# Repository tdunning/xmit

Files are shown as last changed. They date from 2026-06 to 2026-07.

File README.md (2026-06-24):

# XMIT - New tools for old jobs

This repository has design files and (soon) code for a direct synthesis digital 
mode transmitter optimized for use on amateur bands. It should work well up to 
2m. The novelty here relative to other systems like the [QDX](https://qrp-labs.com/qdx.html)
lies in a few areas:

a) the use of [74LVC2G157](https://www.ti.com/lit/ds/symlink/sn74lvc2g157.pdf) to generate differential drive for a differential
driver such as the [THS6232](https://www.ti.com/lit/ds/symlink/ths6232.pdf) which can
directly drive most balanced antennas without a balun at up to about 5W. This design
avoids the need for fancy gate drive or paralleling FETs in favor of SMT packaging everywhere. 

b) the use of SMT inductors and SMT analog switches such as the 
[74lvc2g53](https://www.ti.com/lit/ds/symlink/sn74lvc2g53.pdf) or 
[74lvc1g66](https://www.ti.com/lit/ds/symlink/sn74lvc1g66.pdf).
This change is not earth-shattering, but it allows a much tighter all-SMT design with as much as 80dB suppression of harmonics.
The high degree of suppression is achieved by using a filter tuned to put the response zeros directly on the harmonics
and careful filter layout to suppress parasitic coupling.

# Transmit filtering

The design of the transmit chain uses one of a number of filters to
reject harmonics of the main frequency. One of these filters is
selected using analog switches to suit the desire transmission
frequency. These filters are designed to have minimal attenuation in
each of several amateur bands. Since these bands are relatively
narrow, passband flatness is not a grave concern. The zeros of the
filters are positioned near the second or third harmonics of the
carrier to suppress these frequencies very strongly. Higher harmonics
have nearly 75dB of suppression.

The response curves for the filters designed so far are shown below.

[Filter response curves](images/filters.png)

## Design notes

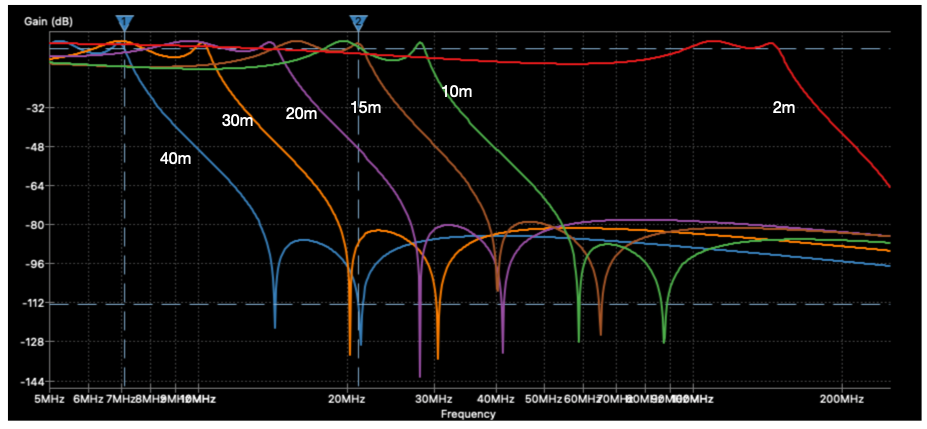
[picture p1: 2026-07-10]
images/filters.png

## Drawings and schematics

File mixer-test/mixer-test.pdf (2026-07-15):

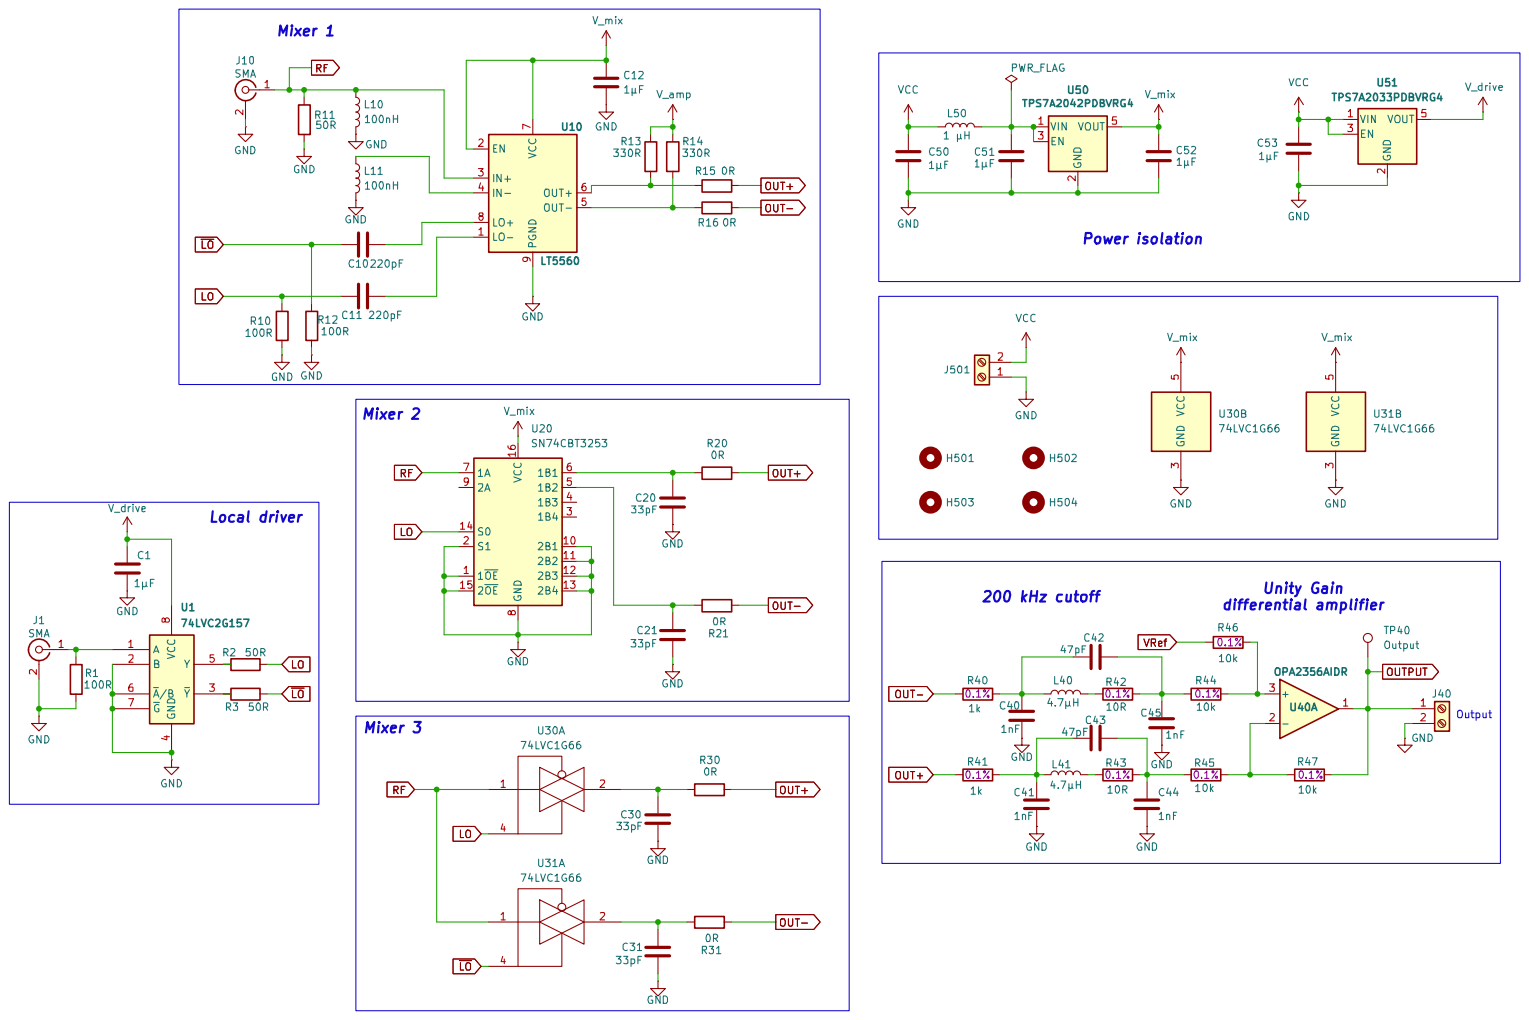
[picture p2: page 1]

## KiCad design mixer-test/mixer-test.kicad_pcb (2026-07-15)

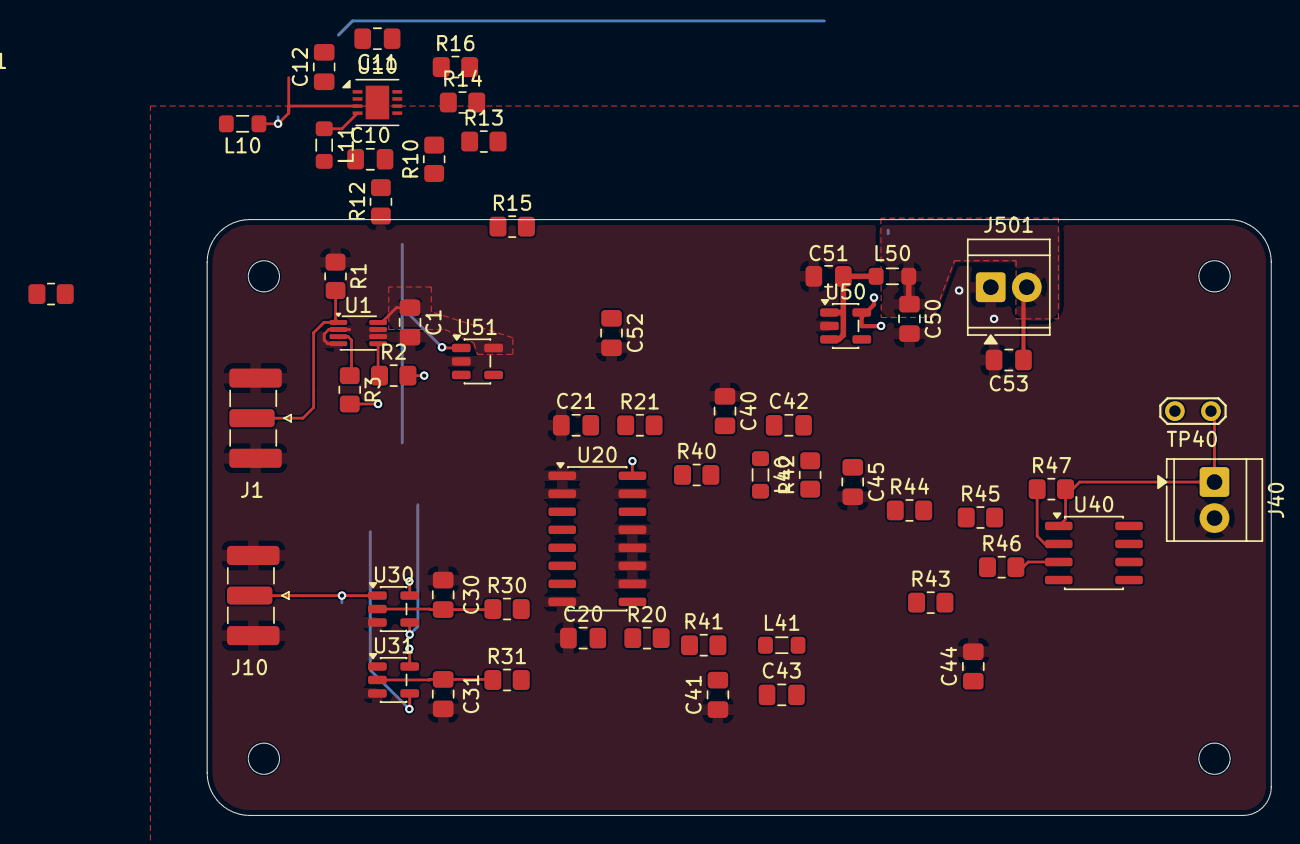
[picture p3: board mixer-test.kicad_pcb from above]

Board: 4 copper layers, 75.0 x 42.0 mm, 62 parts (0 on the bottom side), 32 nets.

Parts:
C1, C12, C50, C51, C52, C53: 1µF; C_0805_2012Metric_Pad1.18x1.45mm_HandSolder
C10, C11: 220pF; C_0805_2012Metric_Pad1.18x1.45mm_HandSolder
C20, C21, C30, C31: 33pF; C_0805_2012Metric_Pad1.18x1.45mm_HandSolder
C40, C41, C44, C45: 1nF; C_0805_2012Metric_Pad1.18x1.45mm_HandSolder
C42, C43: 47pF; C_0805_2012Metric_Pad1.18x1.45mm_HandSolder
H501, H502, H503, H504: MountingHole_2.2mm_M2
J1, J10: SMA; SMA_Samtec_SMA-J-P-H-ST-EM1_EdgeMount
J40: Conn_01x02_Pin; TerminalBlock_TE_282834-2_1x02_P2.54mm_Horizontal
J501: TerminalBlock_TE_282834-2_1x02_P2.54mm_Horizontal
L10, L11: 100nH; L_0805_2012Metric_Pad1.05x1.20mm_HandSolder
L40, L41: 4.7µH; L_0805_2012Metric_Pad1.05x1.20mm_HandSolder
L50: 1 µH; L_0805_2012Metric_Pad1.05x1.20mm_HandSolder
R1, R10, R12: 100R; R_0805_2012Metric_Pad1.20x1.40mm_HandSolder
R2, R3, R11: 50R; R_0805_2012Metric_Pad1.20x1.40mm_HandSolder
R13, R14: 330R; R_0805_2012Metric_Pad1.20x1.40mm_HandSolder
R15, R16, R20, R21, R30, R31: 0R; R_0805_2012Metric_Pad1.20x1.40mm_HandSolder
R40, R41: 1k; R_0805_2012Metric_Pad1.20x1.40mm_HandSolder
R42, R43: 10R; R_0805_2012Metric_Pad1.20x1.40mm_HandSolder
R44, R45, R46, R47: 10k; R_0805_2012Metric_Pad1.20x1.40mm_HandSolder
TP40: Output; TestPoint_2Pads_Pitch2.54mm_Drill0.8mm
U1: 74LVC2G157; VSSOP-8_2.3x2mm_P0.5mm
U10: LT5560; DFN-8-1EP_3x3mm_P0.5mm_EP1.66x2.38mm
U20: SN74CBT3253; SOIC-16_3.9x9.9mm_P1.27mm
U30, U31: 74LVC1G66; SOT-23-5
U40: OPA2356AIDR; SOIC-8_3.9x4.9mm_P1.27mm
U50: TPS7A2042PDBVRG4; SOT-23-5
U51: TPS7A2033PDBVRG4; SOT-23-5

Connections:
GND: C1.2, C12.2, C20.1, C21.1, C30.1, C31.1, C40.1, C41.1, C44.2, C45.2, C50.2, C51.2, C52.2, C53.2, J1.2 (Ext), J10.2 (Ext), J40.2, J501.1, L10.2, L11.2, R1.1, R10.1, R11.1, R12.1, U1.2 (B), U1.4 (GND), U1.6 (~A/B), U1.7 (~G), U10.9 (PGND), U20.1 (1~OE), U20.2 (S1), U20.8 (GND), U20.10 (2B1), U20.11 (2B2), U20.12 (2B3), U20.13 (2B4), U20.15 (2~OE), U30.3 (GND), U31.3 (GND), U50.2 (GND), U51.2 (GND)
LO: C11.1, R2.2, R10.2, U20.14 (S0), U30.4
unnamed: C30.2, R30.1, U30.2
unnamed: C31.2, R31.1, U31.2
unnamed: C40.2, C42.1, L40.1, R40.2
unnamed: C41.2, C43.1, L41.1, R41.2
unnamed: C42.2, C45.1, R42.2, R44.1
unnamed: C43.2, C44.1, R43.2, R45.1
unnamed: J1.1 (In), R1.2, U1.1 (A)
unnamed: L40.2, R42.1
unnamed: L41.2, R43.1
unnamed: R2.1, U1.5 (Y)
unnamed: R3.1, U1.3 (~Y)
unnamed: L11.1, U10.4 (IN-)
unnamed: C10.2, U10.8 (LO+)
unnamed: C11.2, U10.1 (LO-)
unnamed: R13.2, R15.1, U10.6 (OUT+)
unnamed: R14.2, R16.1, U10.5 (OUT-)
unnamed: C20.2, R20.1, U20.6 (1B1)
unnamed: C21.2, R21.1, U20.5 (1B2)
unnamed: R44.2, R46.2, U40.3 (+)
unnamed: R45.2, R47.1, U40.2 (-)
unnamed: C51.1, L50.2, U50.1 (VIN), U50.3 (EN)
OUT+: R15.2, R20.2, R30.2, R41.1
OUT-: R16.2, R21.2, R31.2, R40.1
OUTPUT: J40.1, R47.2, TP40.1 (1_1), U40.1
RF: J10.1 (In), L10.1, R11.2, U10.3 (IN+), U20.7 (1A), U30.1, U31.1
VCC: C50.1, C53.1, J501.2, L50.1, U51.1 (VIN), U51.3 (EN)
V_amp: R13.1, R14.1
V_drive: C1.1, U1.8 (VCC), U51.5 (VOUT)
V_mix: C12.1, C52.1, U10.2 (EN), U10.7 (VCC), U20.16 (VCC), U30.5 (VCC), U31.5 (VCC), U50.5 (VOUT)
~LO: C10.1, R3.2, R12.2, U31.4

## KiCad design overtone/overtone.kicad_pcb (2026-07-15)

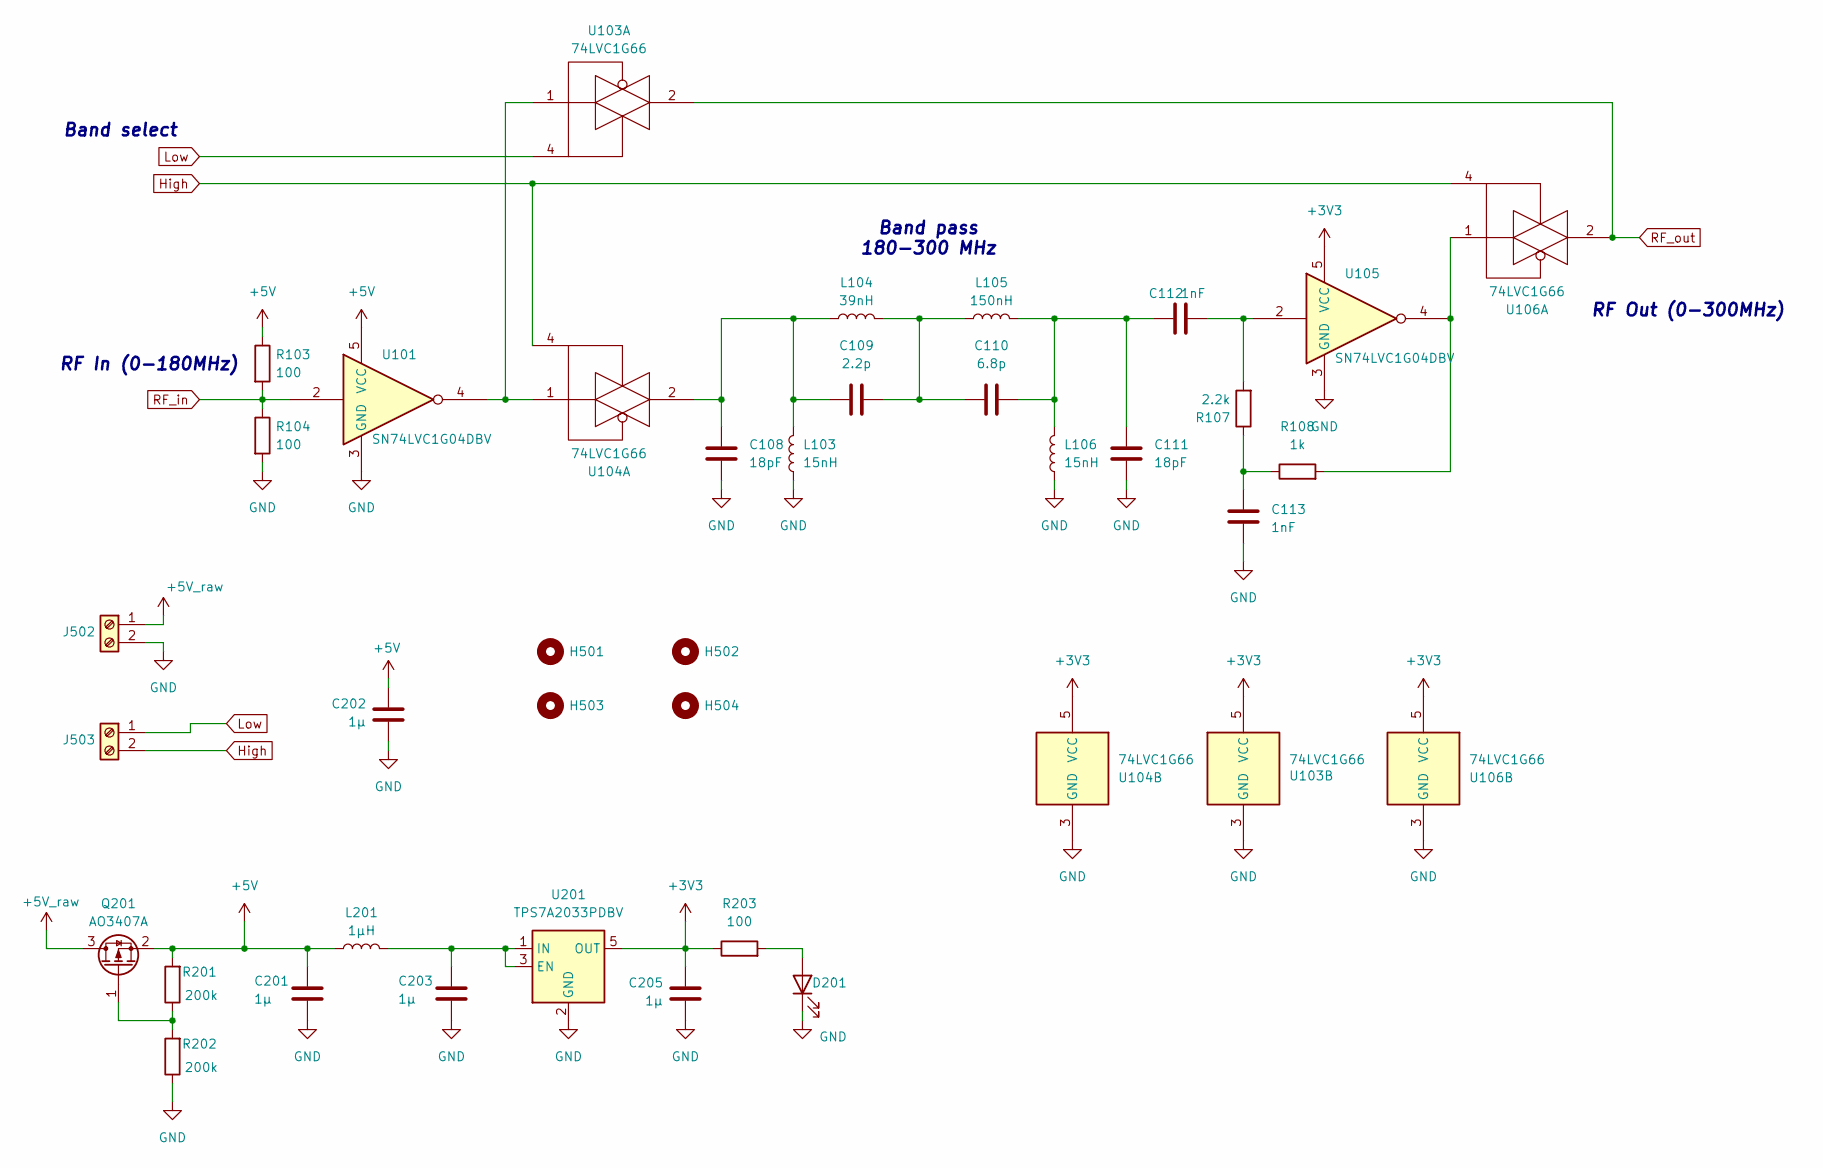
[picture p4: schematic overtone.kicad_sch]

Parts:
C108, C111: 18pF; C_0805_2012Metric_Pad1.18x1.45mm_HandSolder; LCSC Part # C519933
C109: 2.2p; C_0805_2012Metric_Pad1.18x1.45mm_HandSolder; LCSC Part # C519933
C110: 6.8p; C_0805_2012Metric_Pad1.18x1.45mm_HandSolder; LCSC Part # C76626
C112: 1nF; C_0805_2012Metric_Pad1.18x1.45mm_HandSolder
C113: 1nF; C_0805_2012Metric_Pad1.18x1.45mm_HandSolder; LCSC Part # C519933
C201, C202, C203, C205: 1µ; C_0805_2012Metric; LCSC Part # C76645
D201: LED; LED_0603_1608Metric; LCSC Part # C12065
H501, H502, H503, H504: MountingHole_2.2mm_M2
J502, J503: TerminalBlock_TE_282834-2_1x02_P2.54mm_Horizontal
L103, L106: 15nH; L_0805_2012Metric_Pad1.05x1.20mm_HandSolder; LCSC Part # C98996
L104: 39nH; L_0805_2012Metric_Pad1.05x1.20mm_HandSolder; LCSC Part # C98996
L105: 150nH; L_0805_2012Metric_Pad1.05x1.20mm_HandSolder; LCSC Part # C98996
L201: 1µH; L_0805_2012Metric_Pad1.05x1.20mm_HandSolder; LCSC Part # C19533
Q201: AO3407A; SOT-23; LCSC Part # C15155
R103: 100; R_0805_2012Metric_Pad1.20x1.40mm_HandSolder; LCSC Part # C114567
R104: 100; R_0805_2012Metric_Pad1.20x1.40mm_HandSolder; LCSC Part # C17378
R107: 2.2k; R_0805_2012Metric_Pad1.20x1.40mm_HandSolder; LCSC Part # C17378
R108: 1k; R_0805_2012Metric_Pad1.20x1.40mm_HandSolder
R201, R202: 200k; R_0805_2012Metric_Pad1.20x1.40mm_HandSolder; LCSC Part # C17539
R203: 100; R_0603_1608Metric; LCSC Part # C22775
U101, U105: SN74LVC1G04DBV; SOT-23-5; LCSC Part # C45367201
U103, U104, U106: 74LVC1G66; SOT-23-5; LCSC Part # C113518
U201: TPS7A2033PDBV; SOT-23-5; LCSC Part # C7827

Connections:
+3V3: C205.2, R203.1, U103.5 (VCC), U104.5 (VCC), U105.5 (VCC), U106.5 (VCC), U201.5 (OUT)
+5V: C201.2, C202.2, L201.1, Q201.2 (S), R103.1, R201.2, U101.5 (VCC)
+5V_raw: J502.1, Q201.3 (D)
GND: C108.1, C111.1, C113.1, C201.1, C202.1, C203.1, C205.1, D201.1 (K), J502.2, L103.1, L106.1, R104.2, R202.1, U101.3 (GND), U103.3 (GND), U104.3 (GND), U105.3 (GND), U106.3 (GND), U201.2 (GND); also elsewhere on the board
High: J503.2, U104.4, U106.4
Low: J503.1, U103.4
unnamed: C108.2, C109.1, L103.2, L104.1, U104.2
unnamed: C109.2, C110.1, L104.2, L105.1
unnamed: C110.2, C111.2, C112.1, L105.2, L106.2
unnamed: C112.2, R107.2, U105.2
unnamed: C113.2, R107.1, R108.1
unnamed: D201.2 (A), R203.2
unnamed: Q201.1 (G), R201.1, R202.2
unnamed: R108.2, U105.4, U106.1
unnamed: U101.4, U103.1, U104.1
unnamed: C203.2, L201.2, U201.1 (IN), U201.3 (EN)
RF_in: R103.2, R104.1, U101.2; also elsewhere on the board
RF_out: U103.2, U106.2

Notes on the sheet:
Band select
RF In (0-180MHz)
RF Out (0-300MHz)
Band pass 180-300 MHz

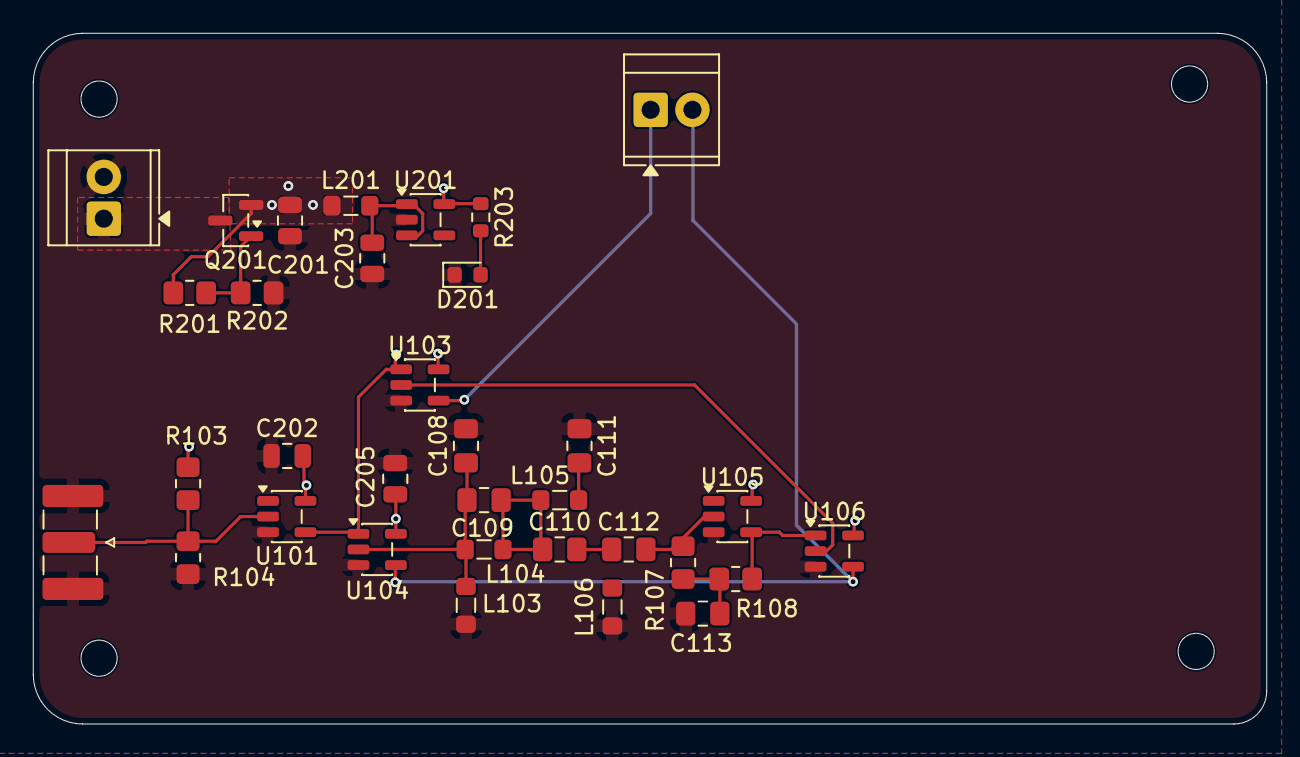
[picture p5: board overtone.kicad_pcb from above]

Board: 4 copper layers, 75.0 x 42.0 mm, 37 parts (0 on the bottom side), 18 nets.

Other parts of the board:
J506: SMA_Samtec_SMA-J-P-H-ST-EM1_EdgeMount

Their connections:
GND: J506.2 (Ext); also elsewhere on the board
RF_in: J506.1 (In); also elsewhere on the board

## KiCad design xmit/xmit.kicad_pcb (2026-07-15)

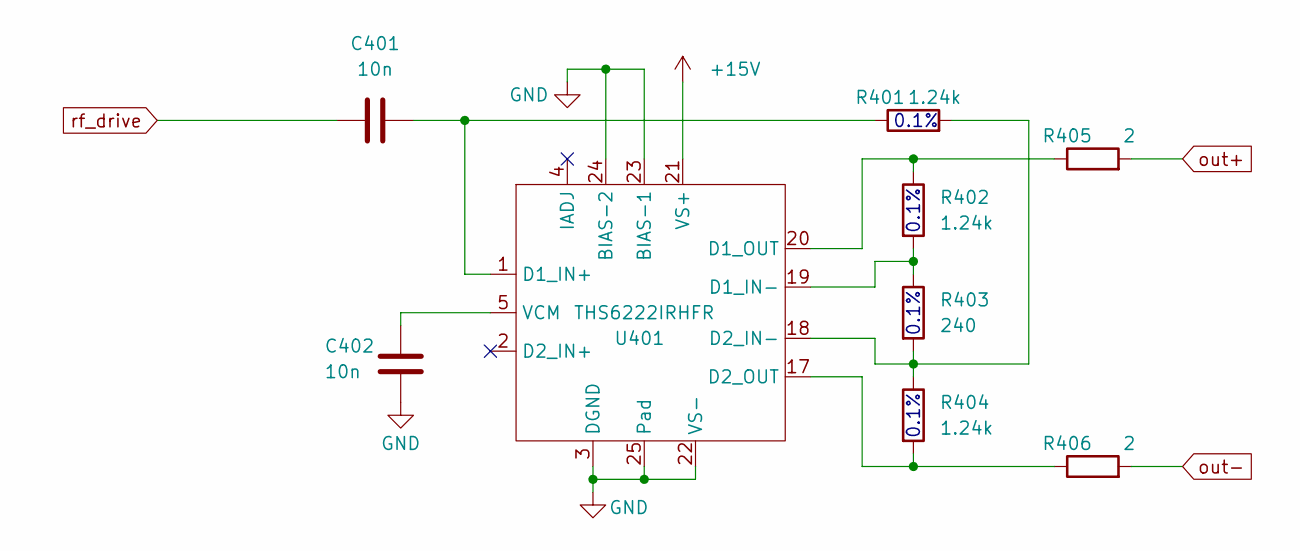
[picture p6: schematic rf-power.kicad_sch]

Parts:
C401, C402: 10n; C_0805_2012Metric_Pad1.18x1.45mm_HandSolder; LCSC Part # C76626
R401, R402, R404: 1.24k; R_0402_1005Metric; LCSC Part # C852604
R403: 240; R_0402_1005Metric; LCSC Part # C17572
R405, R406: 2; R_0805_2012Metric_Pad1.20x1.40mm_HandSolder; LCSC Part # C101983
U401: THS6222IRHFR; QFN-24-1EP_4x5mm_P0.5mm_EP2.65x3.65mm_ThermalVias; LCSC Part # C1855812

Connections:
+15V: U401.21 (VS+); also elsewhere on the board
GND: C402.1, U401.3 (DGND), U401.22 (VS-), U401.23 (BIAS-1), U401.24 (BIAS-2), U401.25 (Pad); also elsewhere on the board
unnamed: C401.2, R401.1, U401.1 (D1_IN+)
unnamed: R402.2, R403.1, U401.19 (D1_IN-)
unnamed: R402.1, R405.1, U401.20 (D1_OUT)
unnamed: R401.2, R403.2, R404.1, U401.18 (D2_IN-)
unnamed: R404.2, R406.1, U401.17 (D2_OUT)
unnamed: C402.2, U401.5 (VCM)
out+: R405.2; also elsewhere on the board
out-: R406.2; also elsewhere on the board
rf_drive: C401.1; also elsewhere on the board

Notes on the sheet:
0.1%

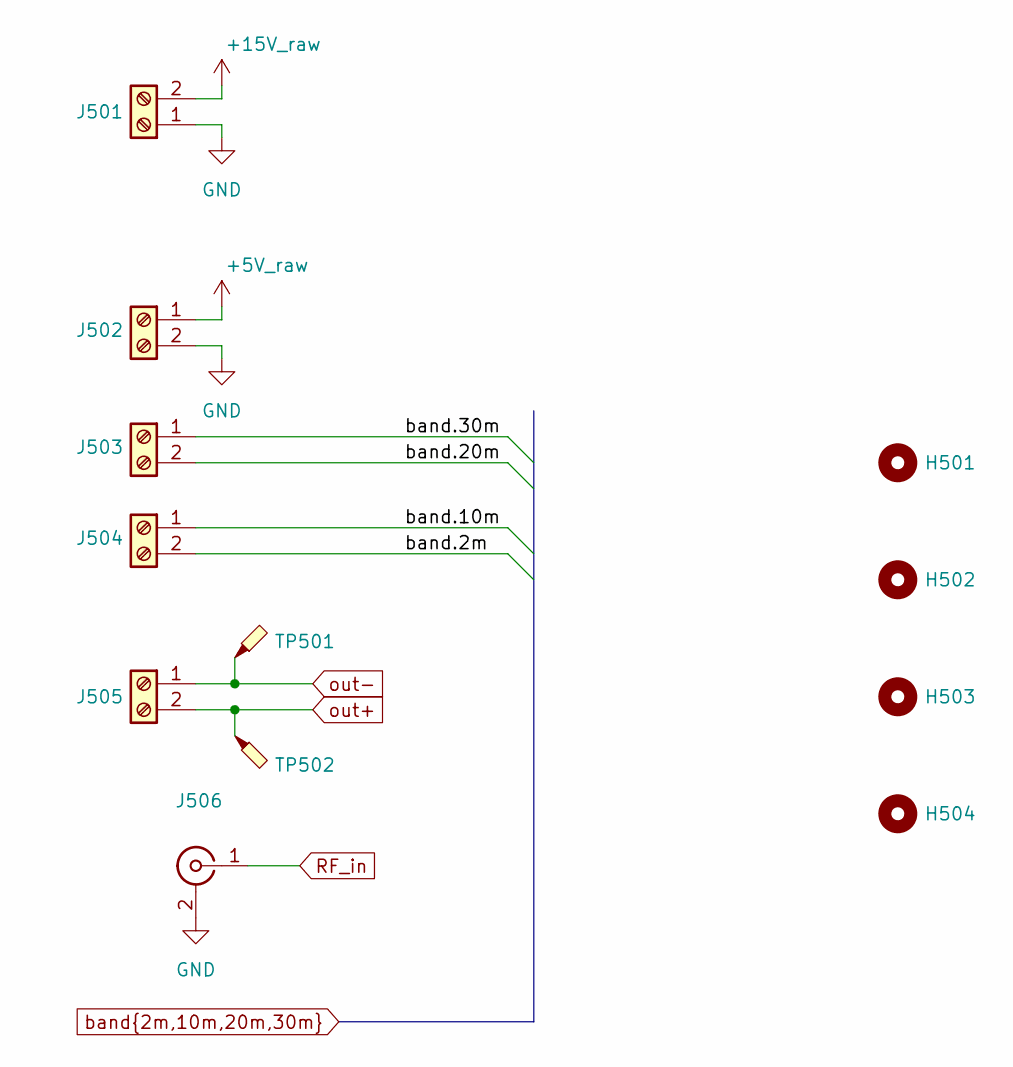
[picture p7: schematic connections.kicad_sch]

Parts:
H501, H502, H503, H504: MountingHole_2.2mm_M2
J501, J502, J503, J504, J505: TerminalBlock_TE_282834-2_1x02_P2.54mm_Horizontal
J506: SMA_Samtec_SMA-J-P-H-ST-EM1_EdgeMount; LCSC Part # C49118400
TP501: TestPoint_2Pads_Pitch2.54mm_Drill0.8mm; LCSC Part # C45367201
TP502: TestPoint_2Pads_Pitch2.54mm_Drill0.8mm; LCSC Part # C113518

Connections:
+5V_raw: J502.1; also elsewhere on the board
+15V_raw: J501.2; also elsewhere on the board
GND: J501.1, J502.2, J506.2 (Ext); also elsewhere on the board
RF_in: J506.1 (In); also elsewhere on the board
band.2m: J504.2; also elsewhere on the board
band.10m: J504.1; also elsewhere on the board
band.20m: J503.2; also elsewhere on the board
band.30m: J503.1; also elsewhere on the board
out+: J505.2, TP502.1 (1_1); also elsewhere on the board
out-: J505.1, TP501.1 (1_1); also elsewhere on the board

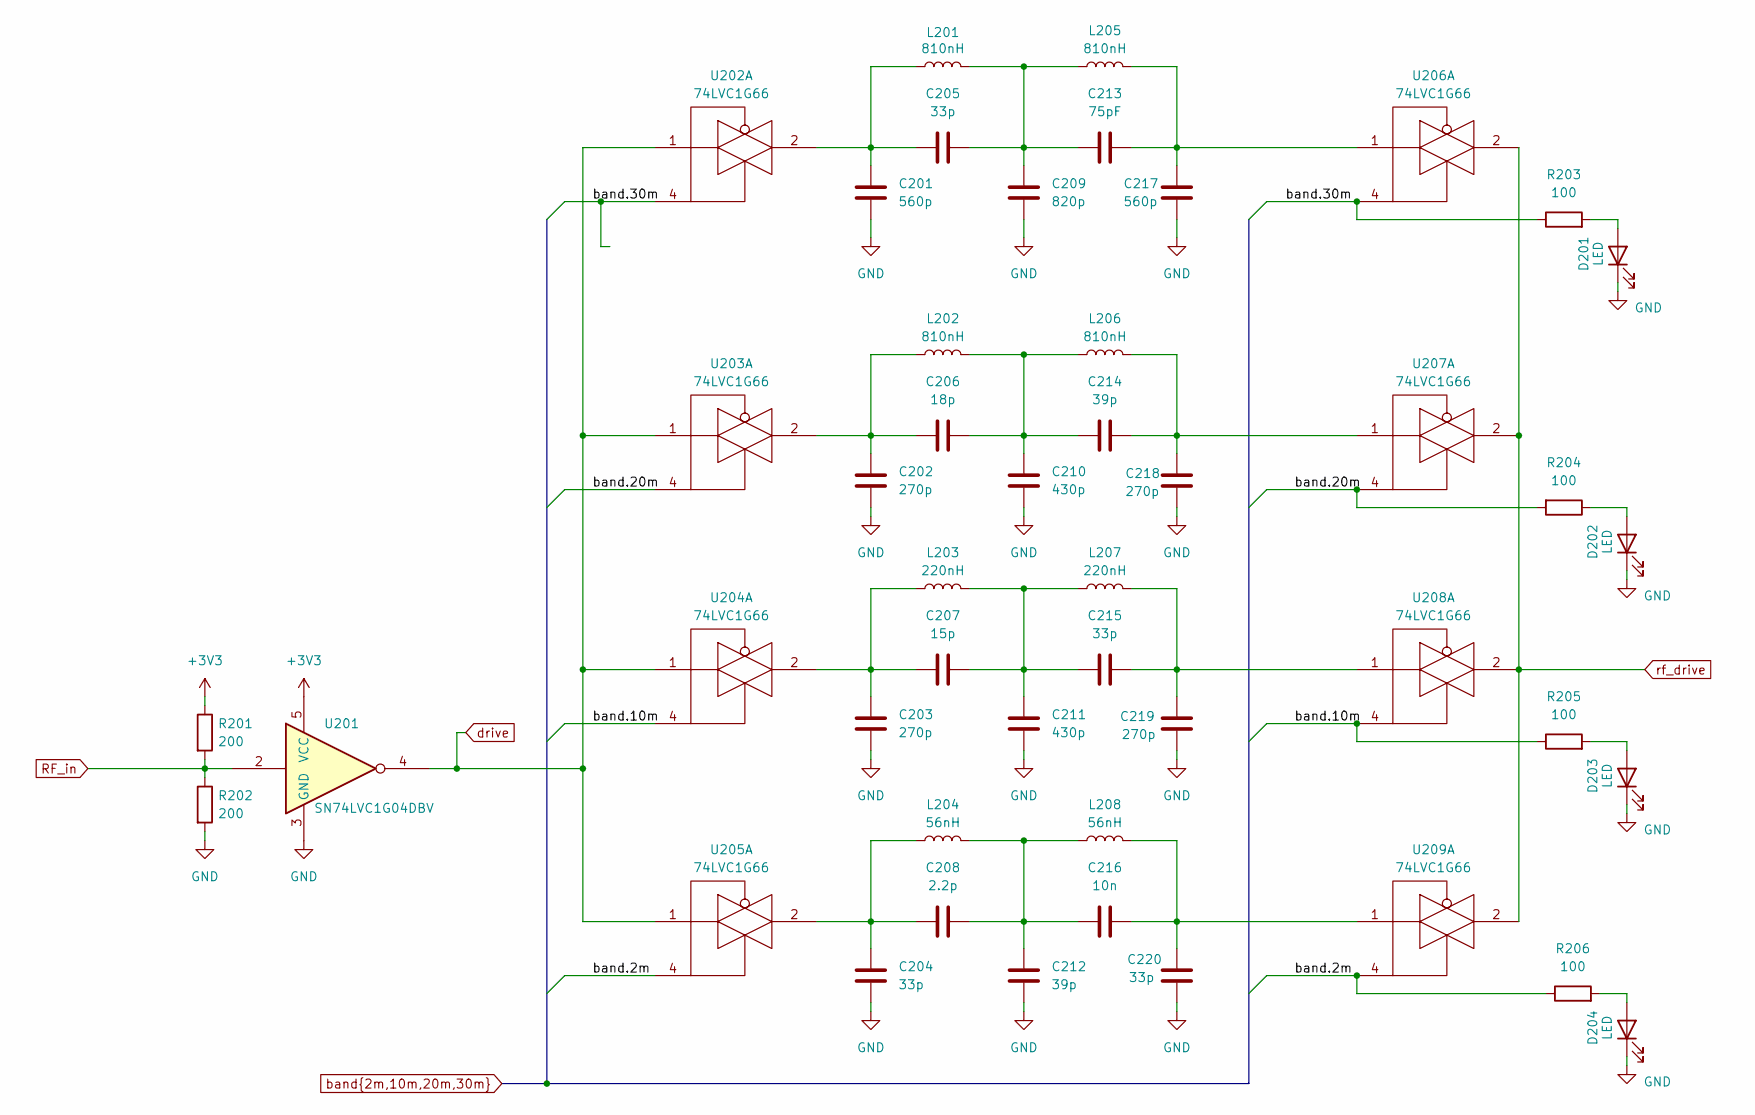
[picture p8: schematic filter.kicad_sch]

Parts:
C201: 560p; C_0805_2012Metric_Pad1.18x1.45mm_HandSolder; LCSC Part # C107119
C202: 270p; C_0805_2012Metric_Pad1.18x1.45mm_HandSolder; LCSC Part # C107106
C203: 270p; C_0805_2012Metric_Pad1.18x1.45mm_HandSolder; LCSC Part # C113828
C204: 33p; C_0805_2012Metric_Pad1.18x1.45mm_HandSolder; LCSC Part # C107115
C205, C215, C220: 33p; C_0805_2012Metric_Pad1.18x1.45mm_HandSolder; LCSC Part # C85970
C206: 18p; C_0805_2012Metric_Pad1.18x1.45mm_HandSolder; LCSC Part # C113825
C207: 15p; C_0805_2012Metric_Pad1.18x1.45mm_HandSolder; LCSC Part # C107110
C208: 2.2p; C_0805_2012Metric_Pad1.18x1.45mm_HandSolder; LCSC Part # C519933
C209: 820p; C_0805_2012Metric_Pad1.18x1.45mm_HandSolder; LCSC Part # C309484
C210: 430p; C_0805_2012Metric_Pad1.18x1.45mm_HandSolder; LCSC Part # C520006
C211: 430p; C_0805_2012Metric_Pad1.18x1.45mm_HandSolder; LCSC Part # C126556
C212: 39p; C_0805_2012Metric_Pad1.18x1.45mm_HandSolder; LCSC Part # C107117
C213: 75pF; C_0805_2012Metric_Pad1.18x1.45mm_HandSolder; LCSC Part # C113832
C214: 39p; C_0805_2012Metric_Pad1.18x1.45mm_HandSolder; LCSC Part # C76645
C216: 10n; C_0805_2012Metric_Pad1.18x1.45mm_HandSolder; LCSC Part # C76626
C217: 560p; C_0805_2012Metric_Pad1.18x1.45mm_HandSolder; LCSC Part # C97881
C218, C219: 270p; C_0805_2012Metric_Pad1.18x1.45mm_HandSolder; LCSC Part # C2986280
D201, D202, D203, D204: LED; LED_0603_1608Metric; LCSC Part # C12065
L201: 810nH; L_0805_2012Metric_Pad1.05x1.20mm_HandSolder; LCSC Part # C139231
L202, L205, L206: 810nH; L_0805_2012Metric_Pad1.05x1.20mm_HandSolder; LCSC Part # C98996
L203, L207: 220nH; L_0805_2012Metric_Pad1.05x1.20mm_HandSolder; LCSC Part # C108960
L204, L208: 56nH; L_0805_2012Metric_Pad1.05x1.20mm_HandSolder; LCSC Part # C98996
R201: 200; R_0805_2012Metric_Pad1.20x1.40mm_HandSolder; LCSC Part # C114567
R202: 200; R_0805_2012Metric_Pad1.20x1.40mm_HandSolder; LCSC Part # C17378
R203, R204, R205, R206: 100; R_0603_1608Metric; LCSC Part # C22775
U201: SN74LVC1G04DBV; SOT-23-5; LCSC Part # C45367201
U202, U203, U204, U205, U206, U207, U208, U209: 74LVC1G66; SOT-23-5; LCSC Part # C113518

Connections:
+3V3: R201.1, U201.5 (VCC); also elsewhere on the board
GND: C201.2, C202.2, C203.2, C204.2, C209.2, C210.2, C211.2, C212.2, C217.2, C218.2, C219.2, C220.2, D201.1 (K), D202.1 (K), D203.1 (K), D204.1 (K), R202.2, U201.3 (GND); also elsewhere on the board
unnamed: C201.1, C205.1, L201.1, U202.2
unnamed: C202.1, C206.1, L202.1, U203.2
unnamed: C203.1, C207.1, L203.1, U204.2
unnamed: C204.1, C208.1, L204.1, U205.2
unnamed: C205.2, C209.1, C213.1, L201.2, L205.1
unnamed: C206.2, C210.1, C214.1, L202.2, L206.1
unnamed: C207.2, C211.1, C215.1, L203.2, L207.1
unnamed: C208.2, C212.1, C216.1, L204.2, L208.1
unnamed: C213.2, C217.1, L205.2, U206.1
unnamed: C214.2, C218.1, L206.2, U207.1
unnamed: C215.2, C219.1, L207.2, U208.1
unnamed: C216.2, C220.1, L208.2, U209.1
unnamed: D201.2 (A), R203.2
unnamed: D202.2 (A), R204.1
unnamed: D203.2 (A), R205.2
unnamed: D204.2 (A), R206.2
RF_in: R201.2, R202.1, U201.2; also elsewhere on the board
band.2m: R206.1, U205.4, U209.4; also elsewhere on the board
band.10m: R205.1, U204.4, U208.4; also elsewhere on the board
band.20m: R204.2, U203.4, U207.4; also elsewhere on the board
band.30m: R203.1, U202.4, U206.4; also elsewhere on the board
drive: U201.4, U202.1, U203.1, U204.1, U205.1
rf_drive: U206.2, U207.2, U208.2, U209.2; also elsewhere on the board

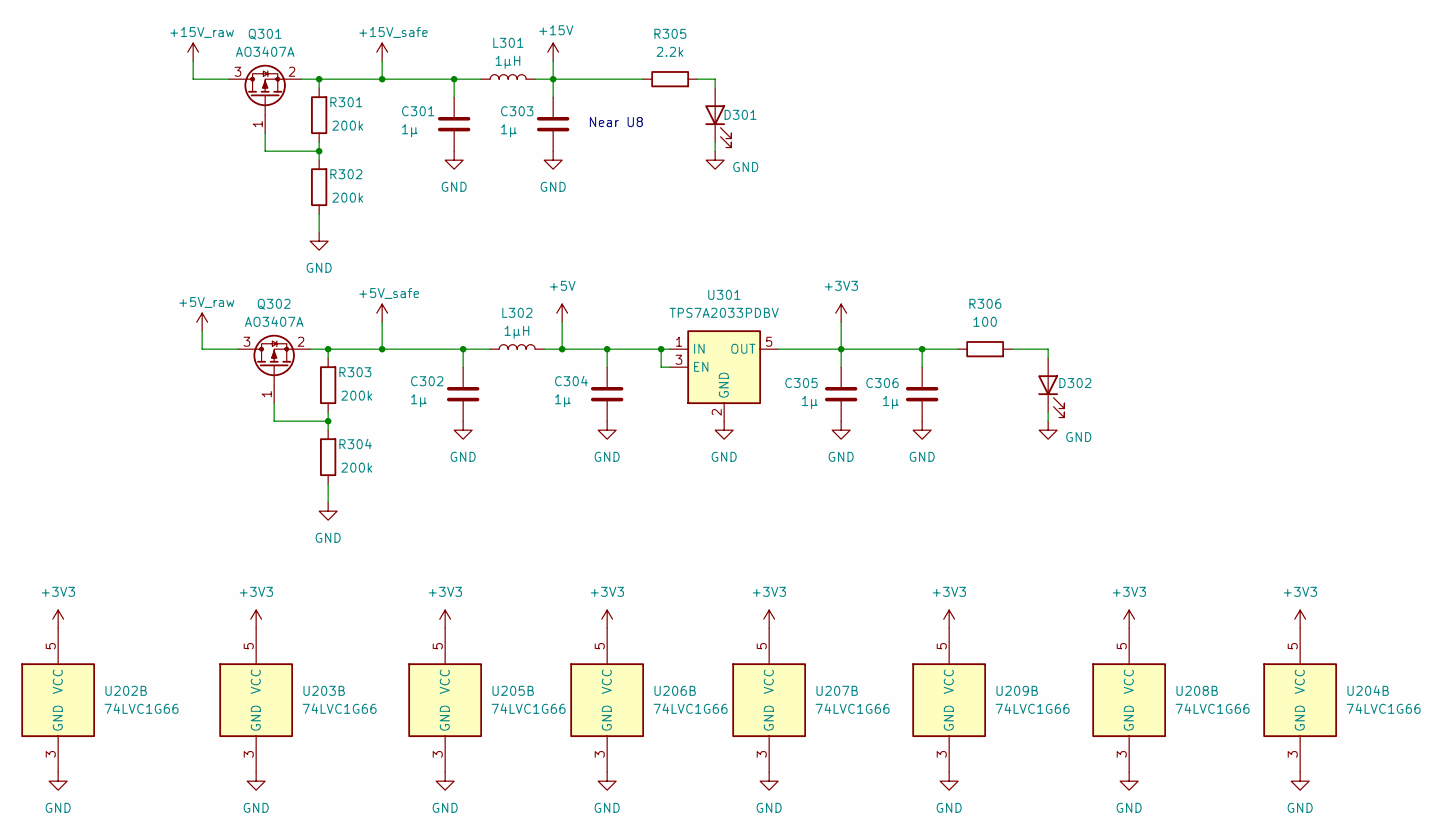
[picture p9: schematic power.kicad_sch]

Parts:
C301, C302, C303, C304, C305, C306: 1µ; C_0805_2012Metric; LCSC Part # C76645
D301, D302: LED; LED_0603_1608Metric; LCSC Part # C12065
L301, L302: 1µH; L_0805_2012Metric_Pad1.05x1.20mm_HandSolder; LCSC Part # C19533
Q301, Q302: AO3407A; SOT-23; LCSC Part # C15155
R301, R302, R303, R304: 200k; R_0805_2012Metric_Pad1.20x1.40mm_HandSolder; LCSC Part # C17539
R305: 2.2k; R_0603_1608Metric; LCSC Part # C113303
R306: 100; R_0603_1608Metric; LCSC Part # C22775
U202, U203, U204, U205, U206, U207, U208, U209: 74LVC1G66; SOT-23-5; LCSC Part # C113518
U301: TPS7A2033PDBV; SOT-23-5; LCSC Part # C7827

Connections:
+3V3: C305.2, C306.2, R306.1, U202.5 (VCC), U203.5 (VCC), U204.5 (VCC), U205.5 (VCC), U206.5 (VCC), U207.5 (VCC), U208.5 (VCC), U209.5 (VCC), U301.5 (OUT); also elsewhere on the board
+5V: C304.2, L302.2, U301.1 (IN), U301.3 (EN)
+5V_raw: Q302.3 (D); also elsewhere on the board
+5V_safe: C302.2, L302.1, Q302.2 (S), R303.2
+15V: C303.2, L301.2, R305.1; also elsewhere on the board
+15V_raw: Q301.3 (D); also elsewhere on the board
+15V_safe: C301.2, L301.1, Q301.2 (S), R301.2
GND: C301.1, C302.1, C303.1, C304.1, C305.1, C306.1, D301.1 (K), D302.1 (K), R302.1, R304.1, U202.3 (GND), U203.3 (GND), U204.3 (GND), U205.3 (GND), U206.3 (GND), U207.3 (GND), U208.3 (GND), U209.3 (GND), U301.2 (GND); also elsewhere on the board
unnamed: D301.2 (A), R305.2
unnamed: D302.2 (A), R306.2
unnamed: Q301.1 (G), R301.1, R302.2
unnamed: Q302.1 (G), R303.1, R304.2

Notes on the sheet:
Near U8

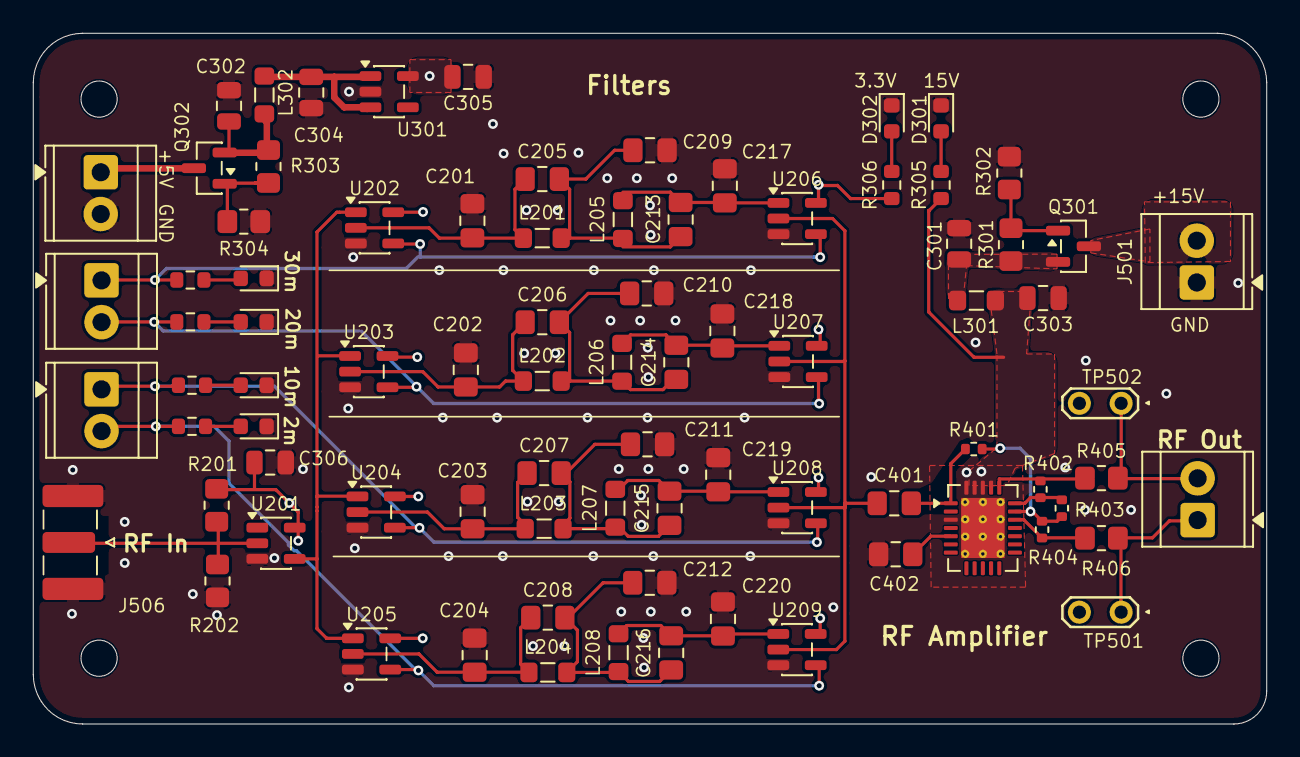
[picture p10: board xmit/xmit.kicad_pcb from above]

Board: 4 copper layers, 75.0 x 42.0 mm, 87 parts (0 on the bottom side), 43 nets.

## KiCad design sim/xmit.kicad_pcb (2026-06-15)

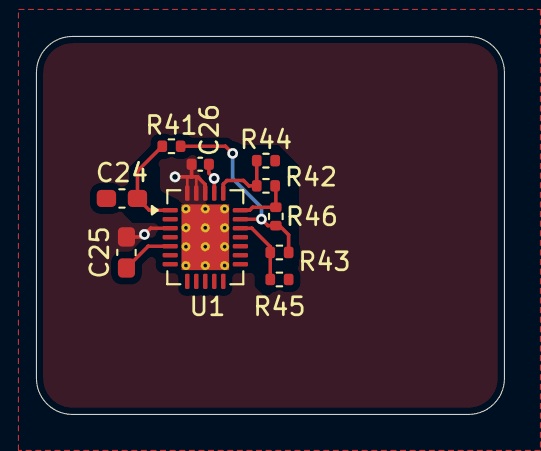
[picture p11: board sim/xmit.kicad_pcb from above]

Board: 4 copper layers, 26.0 x 21.0 mm, 10 parts (0 on the bottom side), 8 nets.

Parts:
C24, C25: 100n; C_0603_1608Metric_Pad1.08x0.95mm_HandSolder
C26: 1u; C_0402_1005Metric
R41, R42, R43: 1.24k; R_0402_1005Metric
R44, R45: 2.5; R_0402_1005Metric
R46: 237; R_0402_1005Metric
U1: QFN-24-1EP_4x5mm_P0.5mm_EP2.65x3.65mm_ThermalVias

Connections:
+12V: C26.2, U1.21 (VS+)
GND: C25.1, C26.1, U1.3 (DGND), U1.22 (VS-), U1.23 (BIAS-1), U1.24 (BIAS-2), U1.25 (Pad)
unnamed: R41.2, R43.1, R46.2, U1.18 (D2_IN-)
unnamed: C24.2, R41.1, U1.1 (D1_IN+)
unnamed: R42.2, R46.1, U1.19 (D1_IN-)
unnamed: R42.1, R44.1, U1.20 (D1_OUT)
unnamed: R43.2, R45.1, U1.17 (D2_OUT)
unnamed: C25.2, U1.5 (VCM)

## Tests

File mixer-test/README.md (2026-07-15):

# Mixer Comparisons

This directory contains design files for PC boards intended to help compare different kinds of mixers, particularly in the HF to VHF regime. 

## The basics

This board has inputs for RF, local oscillator and and baseband outputs (if available). The local oscillator is assumed to be at 3.3V logic levels and is locally buffered to get a differential drive. Test points are available for internal signals.

## The contestants

The mixers available include the LT5560 and Tayloe mixers constructed using SN74CBT3253DR (similar to the FST3253), SN74LVC1G3157, or 74LVC1G66 analog switch. In all cases it is assumed that the desired output is limited to <100kHz. There is no presumption about the frequency of the RF or LO inputs other than they should be near enough to produce a useful baseband output.

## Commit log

2026-06-05 First round WIP on the filters and amplifier
    [filter.kicad_sch, power.kicad_sch, untitled.kicad_sch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]
2026-06-15 WIP commit, but the circuit is nearly done and PCB is beginning for form.
    [connections.kicad_sch, filter.kicad_sch, power.kicad_sch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]
2026-06-15 More realistic simulations
    [RFamp.kicad_sch, filters.kicad_sch, ths6222.kicad_sch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]
2026-06-24 Updated filters and improved amp
    [connections.kicad_sch, filter.kicad_sch, filters.kicad_sch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]
2026-06-24 added filter responses
2026-06-29 Another WIP on transmitter layout. Should be pretty close.
    [691210910002.step, connections.kicad_sch, filter.kicad_sch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]
2026-07-01 More layout cleanup.
    This is a checkpoint before I move all of the power management to a separate board. Next step is to move all power management to a separate board.
    [connections.kicad_sch, filter.kicad_sch, power.kicad_sch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]
2026-07-10 changes up to first spin
    [691210910002.step, BOM-xmit.csv, connections.kicad_sch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]
2026-07-15 WIP adding overtone board design and mixer test board
    [input.csv, mixer-test.kicad_pcb, mixer-test.kicad_sch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]
